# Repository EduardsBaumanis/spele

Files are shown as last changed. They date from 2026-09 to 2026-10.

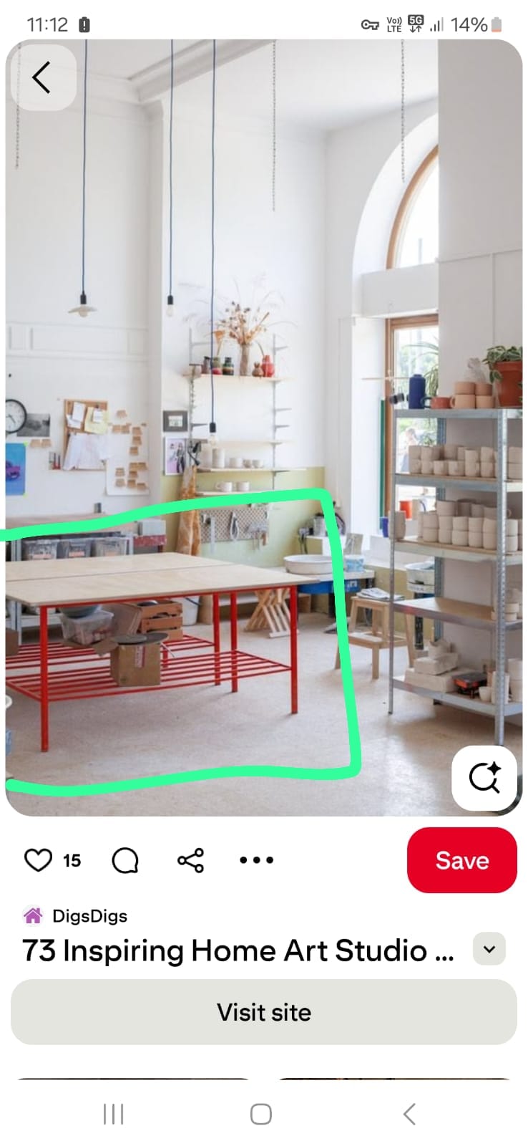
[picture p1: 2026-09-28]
Table.jpeg

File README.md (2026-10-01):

# Keramikas darba galds — vietne GitHub Pages

Latviska dokumentācija galdam 200 × 100 cm. Redakcija F: viena metināta pamatne, 5 cm bērza virsma ar kokskrūvēm no apakšas, astoņas mazas ribas un regulējamas pēdas. Augšējā rāmja nav. Metāla plaukts piemetināts kājām. Visi izgatavošanas izmēri centimetros.

Atveriet **[index.html](index.html)**. Vietnē ir 3D modelis, visi trīs PDF un septiņi SVG rasējumi ar lapu izvēli un tuvināšanu, detaļu tabula un lasāms apraksts. PDF priekšskatījumi ir lokāli attēli; vietnei nav vajadzīgs servera kods, ārējas bibliotēkas vai pārlūka PDF spraudnis. Oriģinālie PDF un SVG ir pieejami lejupielādei.

3D skatā poga **Sadalīt detaļās** atdala visas 37 tērauda detaļas, galda saplākšņa virsmu un četras pēdas; skats automātiski ietilpina visu konstrukciju. Detaļu izmēri saglabājas, atdalījuma attālumi ir ilustratīvi. Poga **Samontēts** atjauno salikto galdu. Atsevišķais slīdnis paceļ tikai noņemamo virsmu. Detaļu sadalījums ir apskates ilustrācija: metinātā pamatne dzīvē neizjaucas.

## Publicēšana GitHub Pages

1. Pievienojiet repozitorijam `index.html`, `.nojekyll`, visu `site-assets/` un `pottery-table/` mapi. Lietojiet šeit esošo mapju struktūru. ZIP arhīvs publicēšanai nav nepieciešams.
2. Nosūtiet šos failus uz sava repozitorija `main` zaru.
3. GitHub atveriet **Settings → Pages → Build and deployment**.
4. Izvēlieties **Deploy from a branch**, zaru **main** un mapi **/(root)**, tad **Save**.
5. Sagaidiet GitHub norādīto vietnes adresi. Projekta vietnei tā parasti ir `https://LIETOTĀJS.github.io/REPOZITORIJS/`.

Visas vietējās saites ir relatīvas, tāpēc vietne darbojas arī repozitorija apakšceļā. Nav vajadzīgs domēns vai GitHub Actions konfigurācija. Šajā uzdevumā vietne ir sagatavota; tā nav nosūtīta uz GitHub vai publicēta.

[GitHub oficiālā publicēšanas instrukcija](https://docs.github.com/en/pages/getting-started-with-github-pages/configuring-a-publishing-source-for-your-github-pages-site).

## Lokāla apskate

Var atvērt `index.html` tieši pārlūkā. Lai pārbaudītu tāpat kā tīmeklī, no šīs mapes palaidiet:

```sh
python3 -m http.server 8000
```

Tad atveriet `http://localhost:8000`. Vietne nelieto `fetch`, tādēļ lokālajiem datiem nav nepieciešams ārējs serveris.

## Dokumentācijas atjaunošana

Izmēri un modeļa dati: `pottery-table/source/design.py`. Rasējumi: `pottery-table/source/drawings.py`. Apraksts: `pottery-table/construction-guide.md`. Vietnes avoti: `pottery-table/source/site/` un `pottery-table/source/website.py`.

Ģenerēšanai vajadzīgs Python 3, `reportlab`, `svglib`, `pypdf`, `pymupdf` un DejaVu Sans vai Windows Arial. No repozitorija saknes:

```sh
python -m pip install -r pottery-table/source/requirements.txt
python -X utf8 pottery-table/source/build.py
```

Komanda atjauno CSV, CAD, visus PDF un SVG, PDF priekšskatījumus, vietni un `pottery-table-workshop-package.zip`. Priekšskatījumi tiek pārrenderēti, ja PDF lapu saturs mainās. Pēc ģenerēšanas publicējiet arī atjaunotos statiskos failus.

Plaukta 200 kg slodze ir projektēšanas un pieņemšanas mērķis, nevis sertificēta nestspēja. Pirms lietošanas jāpārbauda izgatavotie mezgli un pakāpeniska slogošana; pilnas norādes aprakstā.

Pamatne nav izjaucama (180 × 80 × 73 cm); virsma ir noņemama. Pirms izgatavošanas pārbaudiet pārvietošanas ceļu. Gatavam galdam pārbaudiet šuves, pēdu līmeni un šūpošanos, pēc tam slodzi palieliniet pakāpeniski.

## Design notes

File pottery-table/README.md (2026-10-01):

# Keramikas galds — vienkāršā redakcija F

Virsma 200 × 100 × 5 cm, augstums 78 cm. Viena sametināta tērauda pamatne ar plauktu, četras balsta plāksnes, astoņas nelielas ribas un parastas kokskrūves no apakšas. Augšējā rāmja, frēzētu ielaidumu un skrūvētu plaukta savienojumu nav. Kopā 37 tērauda detaļas.

Atveriet [dokumentu vietni](../index.html) vai [3D modeli](index.html). Virsmu var noņemt; kājas un plaukts neizjaucas. Pirms izgatavošanas pārbaudiet viengabala pamatnes 180 × 80 × 73 cm pārvietošanas ceļu.

- [Pilnais PDF](workshop-package.pdf) un [septiņi A3 rasējumi](drawings.pdf).
- [Vienkāršā būvēšanas secība](construction-guide.md) un [izmēru pārbaude](verification.md).
- [Tērauda detaļas](cutting-list.csv), [skrūves un pēdas](hardware-list.csv), [sagatavju sadalījums](stock-cutting.csv), [urbumi](drilling-coordinates.csv).
- [Nesūtīts cenu pieprasījuma melnraksts](supplier-quote-lv.txt).
- [OpenSCAD modelis](model/table.scad) un [modeļa dati](model/design.json).

Visi izgatavošanas izmēri cm. CSV semikols un decimālais komats; JSON/CAD decimālais punkts. Rasējumi: S01 kopskats, S02 balsti, S03 augstumi, S04 kāju galvas, S05 plaukts, S06 kokskrūves, S07 metināšanas secība. Izmantojiet tikai redakciju F.

200 kg plauktam un 200 kg vienmērīgi uz virsmas ir projektēšanas mērķi, nevis sertificēta nestspēja. Pārbaudiet šuves, pēdu saskari un tukša galda šūpošanos; slodzi palieliniet pakāpeniski. Šaubīgas šuves parādiet pieredzējušam metinātājam. Masa un pārbaudes robežas dotas verification.md.

## Atkārtota ģenerēšana

Python 3; reportlab, svglib, pypdf un pymupdf; DejaVu Sans vai Windows Arial. No projekta saknes:

```sh
python -m pip install -r pottery-table/source/requirements.txt
python -X utf8 pottery-table/source/build.py
```

Komanda atjauno CSV, modeli, vietni, PDF, SVG, priekšskatījumus un ZIP. Avoti source/design.py, source/drawings.py un construction-guide.md. 3D skatā poga **Sadalīt detaļās** atdala visas 37 tērauda detaļas, virsmu un četras pēdas, automātiski ietilpinot tās skatā. **Samontēts** atjauno salikto galdu. Detaļu izmēri nemainās; sadalījums ir tikai ilustrācija, jo pamatne ir sametināta. Atsevišķais slīdnis paceļ tikai noņemamo virsmu. OpenSCAD modelis šajā vidē nav kompilēts.

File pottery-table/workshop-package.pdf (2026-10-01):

PT-200 / IZGATAVOŠANAS DOKUMENTĀCIJA

Redakcija F · 2026-10-01 · visi izmēri cm | 1

# Vienkāršs, masīvs keramikas galds

Redakcija F · 2026. gada 1. oktobris.

Virsma 200 × 100 × 5 cm; augstums 78 cm. Visi izmēri šeit ir centimetros. M16 ir standarta vītnes apzīmējums. Tas pats 50 mm bērza saplāksnis, vienkāršāka izgatavošana.

## Ko būvējam

Vienu sametinātu tērauda pamatni ar četrām kājām un zemu metāla plauktu. Uz kājām četras plakanas balsta plāksnes; pie katras divas nelielas trīsstūra ribas. Virsmu pieskrūvē no apakšas ar parastām kokskrūvēm un paplāksnēm. Darba virspuse paliek gluda.

Augšējā rāmja nav. Nav jāfrēzē metāla ielaidumi, jāurbj cauri virsmai vai jāsalāgo skrūvēti plaukta mezgli. Kājas un plaukts neizjaucas; noņemt var tikai virsmu un izskrūvēt pēdas. Tērauda detaļu skaits samazināts no 69 līdz 37.

Pirms metināšanas pārbaudiet, vai viena 180 × 80 × 73 cm pamatne izies pa durvīm un pagriezieniem līdz darba vietai. Ja neizies, sametiniet to galīgajā telpā vai pārskatiet transportēšanas risinājumu pirms materiālu sagatavošanas. Gatavā virsma ir lielāka un jāienes atsevišķi.

## Kas jāsagādā

- Gatavā bērza saplākšņa virsma 200 × 100 × 5, līdzena un bez atslāņojumiem; izgriežama no 250 × 125 × 5 loksnes.
- Kājas: 4 gab. SHS 6 × 6 × 0,3, garums 68,4.
- Plaukta garensijas: 2 gab. RHS 8 × 4 × 0,3, garums 156; 8 vertikāli.
- Plaukta gala sijas: 2 gab. tā paša profila, garums 54; 8 vertikāli.
- Plaukta šķērslīstes: 13 gab. RHS 6 × 4 × 0,3, garums 27; 4 vertikāli.
- Kāju augšējās plāksnes P01: 4 gab. 20 × 20 × 0,8, katrai četri Ø0,9 caurumi. Centri 3 no malām.
- Kāju pēdu plāksnes P02: 4 gab. 6 × 6 × 0,8, katrai Ø1,8 caurums centrā un M16 metināms uzgrieznis.
- Ribas P05: 8 vienādi taisnleņķa trīsstūri ar katetēm 6 un 6, biezums 0,6.
- Virsmai: 16 kvalitatīvas seškanšu galvas kokskrūves Ø0,8 × 4 un 16 paplāksnes, aptuveni 0,2 biezas. Skrūves garums dots zem galvas. Nelietot ģipškartona skrūves.
- 4 M16 regulējamas pēdas ar platiem gumijotiem paliktņiem ap Ø8 un kontruzgriežņiem. Pēdas deklarētā nestspēja vismaz 300 kg katrai pie izmantotā regulējuma.

Vienkāršākais ir metāla tirgotājam pasūtīt gatavos taisnos griezumus, trīsstūrus un izurbtās plāksnes. P01 var izgatavot pēc viena urbšanas šablona; P02 ar uzgriezni var palūgt sagatavot metinātājam. Nav vajadzīga precīza frēzēšana. Pilnie saraksti ir CSV un PDF pielikumā; cenas pieprasījuma melnraksts nav nosūtīts.

Caurulēm pietiek ar vienu 600 cm sagatavi no katra no trim profiliem. Griešanas sarakstā ierēķināts 0,3 zāģējums un 2 rezerve galiem. Profili necinkoti S235; pirms metināšanas notīrīt savienojumu vietas.

## 1. Izveidojiet četras kājas

Piemetiniet M16 uzgriezni P02 augšpusē, kamēr plāksne vēl ir atsevišķi. Pārbaudiet pēdas ieskrūvēšanos. Tad piemetiniet P02 pie kājas apakšas, uzgriezni atstājot caurules iekšpusē.

P01 centrējiet uz kājas augšgala. Katrā kājā pievienojiet divas 6 × 6 trīsstūra ribas: vienu garuma, otru platuma virzienā, abas vērstas uz galda vidu. S04 parādīts pirmais stūris; pārējiem stūriem izvietojumu spoguļojiet. Šuves savieno abas ribas katetes ar kāju un augšējo plāksni. Skrūvju caurumi paliek brīvi stūros.

Caurules gala savienojumu ar plāksni un ribas sametiniet pilnībā, ne tikai pieķeriet. Strādājiet pārmaiņus pretējās pusēs, lai plāksni mazāk savērptu. Tai cieši jāpieguļ virsmai. Uz 0,3 sienas vispirms izmēģiniet metinājumu tāda paša profila atgriezumā; stiprības šuves nenoslīpējiet plānas.

## 2. Sametiniet pamatni ar plauktu

Vispirms izgatavojiet divus vienādus galus: divas kājas un viena 54 cm gara S02 starp tām. Sijas apakša ir 11,2 virs kājas caurules apakšgala. Ar nominālajām pēdām tas ir 15 virs grīdas, sijas augša 23. Iestatīšanai izmantojiet vienādus atgriezumus kā starplikas.

S02 gali tieši pieguļ kāju iekšējām sienām. Caurules griež taisni; nav slīpu stūru. Pirms griešanas pārbaudiet faktisko aili, bet saglabājiet kāju centru attālumu 60. Galiem cieši jāpieguļ; lielas spraugas neaizpildiet ar nejaušiem metinājuma pikučiem.

Savienojiet abus galus ar divām 156 cm S01 garensijām. To ārmalas ir 32,5 un 67,5 no vienas garās virsmas malas; plaukta kopējais platums 35. Garensijas piemetina starp gala siju iekšējām plaknēm. Visiem četriem nesošajiem profiliem 8 cm vertikāli.

Ievietojiet 13 šķērslīstes, katru 27 garu, ar 4 cm vertikāli. To augšas vienā līmenī ar garensiju augšām. Pirmās līstes ārmalu novietojiet 25 no galda gala; starp līstēm atstājiet 6 spraugu. Vienu 6 cm platu atgriezumu lietojiet kā atkārtojamu šablonu. Režģa zona sanāk 150 × 35.

Vispirms visu tikai pieķeriet. Pārbaudiet taisnleņķus, vienādu augstumu un abas kāju centru diagonāles: nomināli 170,88, starpība ne vairāk par 0,2. Četrām augšējām plāksnēm jāatrodas vienā plaknē. Tad metiniet pārmaiņus pretējās pusēs. Gala siju savienojumus ar kājām un pārējos nesošos savienojumus sametiniet pa pieejamo perimetru. Gatavam galdam ar pieķeršanas punktiem nepietiek.

Slēgtajiem profiliem paredzētos ventilācijas urbumus skatiet koordinātu sarakstā; atveres izveido pirms profila aizmetināšanas. Ja pamatni pulverkrāsosiet, ventilāciju un noteci saskaņojiet ar krāsotāju. Metāla režģa augšējās malas noslīpējiet gludas, lai tās neplēstu māla maisus.

## 3. Pieskrūvējiet virsmu no apakšas

Saplākšņa malas noapaļojiet vai rūpīgi noslīpējiet. Aizsargājiet abas puses, malas un urbumus pret mitrumu ar izvēlētu apdari pēc tās ražotāja instrukcijas.

Droši atbalstiet virsmu ar apakšu uz augšu un uzlieciet pamatni. Tā jānovieto centrā: P01 ārmalas 10 no virsmas malām; kāju centri 20 no malām. Pārnesiet 16 caurumu vietas caur P01. Ja izmantojat koordinātas: X=13;27;173;187 un Y=13;27;73;87, visas kombinācijas. Tie ir skati no augšas; uz apgrieztas virsmas orientāciju pārbaudiet ar pašu pamatni.

Izurbiet priekšurbumus no apakšas ar dziļuma ierobežotāju līdz 3,2. Diametru nosaka izvēlētās kokskrūves ražotājs; izmēģiniet vienu skrūvi tāda paša saplākšņa atgriezumā. Pievienojiet paplāksnes un ieskrūvējiet Ø0,8 × 4 kokskrūves. Nomināli 0,8 plāksne + 0,2 paplāksne + 3 ieskrūvējums = 4, tāpēc līdz virspusei paliek ap 2 cm. Cauri darba virsmai nav jāurbj.

Pēdējo pievilkšanu veiciet ar rokas atslēgu, līdz savienojums ciešs. Nesabojājiet vītni kokā ar pārmērīgu spēku. Starp plāksni un virsmu nelieciet mīkstu putu lenti. Virsmas svaru balsta plāksnes; skrūves notur to vietā. Smago galdu ceļ aiz tērauda pamatnes, nevis saplākšņa malas. Ja virsmu bieži noņemsiet, pārbaudiet, vai kokskrūvju vietas nav izļodzītas.

## 4. Noregulējiet pēdas un pārbaudiet galdu

Nominālais augstums: 3 pēda + 0,8 P02 + 68,4 kāja + 0,8 P01 + 5 virsma = 78. Ja faktiskās virsmas biezums ir t, pēdas augstums līdz P02 apakšai ir 8 − t. Pie t=4,81–5,15 tas ir 3,19–2,85. Izvēlieties pēdu, kurai šajā diapazonā paliek pilna uzgriežņa vītnes saķere. Augstuma maiņa nedaudz maina arī plaukta augstumu.

- Vēl pirms virsmas uzlikšanas apskatiet šuves un pārbaudiet tukšo pamatni. Šaubīgu šuvi parādiet pieredzējušam metinātājam, īpaši gala sijas savienojumu ar kāju.
- Galīgajā vietā noregulējiet visas četras pēdas, lai katra stingri balstās uz grīdas. Fiksējiet kontruzgriežņus. Spiediet pārmaiņus katru galda stūri: nedrīkst būt klaboņas vai šūpošanās uz trim kājām.
- Stingri piespiediet tukšu galdu no abām garajām un abām īsajām malām. Šuvēs un plākšņu savienojumos nedrīkst būt redzamas kustības. Ja viss galds slīd, pārbaudiet pēdu saķeri ar grīdu; vajadzības gadījumā izmantojiet grīdai piemērotu fiksāciju.
- Māla maisus pievienojiet pakāpeniski un vienmērīgi pa režģi, nevis visus vienā punktā. Vērojiet šuves, plaukta un virsmas lieci. Pie plaisāšanas, kustības vai paliekošas deformācijas pārtrauciet un novērsiet cēloni.
- Pārbaudiet kokskrūves un pēdu kontruzgriežņus pēc pirmās lietošanas nedēļas un pēc pārvietošanas.

200 kg uz plaukta un 200 kg vienmērīgi uz virsmas saglabāti kā projektēšanas mērķi, nevis pārbaudīta vai sertificēta nestspēja. Metinājumu kvalitāti un faktiskās plātnes lieci nevar garantēt ar detaļu sarakstu; smago paredzēto slodzi izmēģina tikai pēc savienojumu apskates. Galds nav pakāpiens vai sēdvieta.

## Lietošana un rasējumi

Sēdvietu skaitu un izvietojumu pielāgojiet 200 × 100 cm virsmai. Pirms gala metināšanas ar īstajiem krēsliem pārbaudiet vietu ceļiem un pēdām; zemās gala sijas atrodas 15–23 virs grīdas. Divi noņemami 60 × 45 × 2,1 saplākšņa dēļi ar audeklu un mīkstām skavām der māla mīcīšanai. Pēc darba tos noņem un izžāvē.

S01 kopskats; S02 balstu izvietojums; S03 augstumi; S04 vienkāršās kāju galvas; S05 plaukts; S06 kokskrūves no apakšas; S07 metināšanas secība. Precīzie izgatavošanas izmēri ir rasējumos un CSV. Izmantojiet tikai redakciju F; iepriekšējās versijas detaļas nav jāsajauc ar šo.

Aprēķinu piezīmes un automātisko izmēru pārbaužu rezultāti ir verification.md un PDF pielikumā. PDF drukājot pārbaudiet 5 cm kontroles līniju. JSON un CAD viena vienība ir 1 cm. Bērza saplākšņa ražotāja informācija: https://www.finieris.com/products/riga-ply/ .

# Tērauda detaļu saraksts

Gatavie izmēri cm. Taisni gali, izņemot trīsstūrveida ribas. Necinkots S235. Zāģējums pieskaitāms materiāla patēriņam.

Poz. | Detaļa | Profils, cm | Gab. | Gatavais izmērs, cm
L01 | Galda kāja | SHS 6×6×0,3 | 4 | 68,4
S01 | Plaukta garensija; 8 vertikāli | RHS 8×4×0,3 | 2 | 156
S02 | Plaukta gala šķērssija; 8 vertikāli | RHS 8×4×0,3 | 2 | 54
S03 | Plaukta šķērslīste; 4 vertikāli | RHS 6×4×0,3 | 13 | 27
P01 | Kājas balsta plāksne tieši zem saplākšņa | Plāksne 0,8 | 4 | 20 × 20 × 0,8
P02 | Kājas apakšējā plāksne | Plakandzelzs 6×0,8 | 4 | 6 × 6 × 0,8
P05 | Kājas stingrības riba; katetes 6 un 6 | Plāksne 0,6 | 8 | Katetes 6 un 6; biezums 0,6

# Cauruļu sagatavju sadalījums

600 cm sagataves; 0,3 cm zāģējums katrai detaļai; kopā 2 cm rezervē galiem. Plakandzelzs un trīsstūru sagataves aprēķina atsevišķi.

Profils, cm / sagatave | Gatavie garumi, cm | Atlikums, cm
SHS 6×6×0,3 / 1 | L01: 68,4; L01: 68,4; L01: 68,4; L01: 68,4 | 323,2
RHS 8×4×0,3 / 1 | S01: 156; S01: 156; S02: 54; S02: 54 | 176,8
RHS 6×4×0,3 / 1 | S03: 27; S03: 27; S03: 27; S03: 27; S03: 27; S03: 27; S03: 27; S03: 27; S03: 27; S03: 27; S03: 27; S03: 27; S03: 27 | 243,1

## Norādes piegādātājam

Visi norādītie izmēri ir gatavie detaļu izmēri centimetros. Pieskaitīt faktisko zāģējumu, saglabājot detaļu garumus. Marķēt detaļu pozīcijas un noņemt atskabargas. Ja zāģējumam vai galu apgriešanai vajadzīga lielāka rezerve, sadalījumu pārrēķināt.

Atsevišķi precizēt maksu par pilnām sagatavēm, plakandzelzs minimumus, trīsstūru griešanu un piegādi. Apmaksātos atlikumus atdot pasūtītājam. Pievienotajā nesūtītajā pieprasījumā vēl jāieraksta pasūtītāja kontaktinformācija.

# Stiprinājumi un saplāksnis

Pirms urbšanas izvēlēties īstos balstus, metināmos uzgriežņus un kokskrūves ar paplāksnēm. Sausajā montāžā pārbaudīt skrūvju garumus. Skaits gabalos.

Poz. | Sk. | Apraksts | Montāžas un iegādes piezīme
H07 | 4 | M16 metināms uzgrieznis | Kājas iekšpusē virs P02; izvēlēties pirms metināšanas.
H08 | 4 | M16 regulējams balsts; paliktnis ap Ø8 cm; vismaz 300 kg katram | Paliktnis ne augstāks par 2 cm; kāts vismaz 6 cm; regulējums 2,85–3,19 cm no grīdas līdz P02 apakšai.
H09 | 4 | M16 plāns kontruzgrieznis; nomināli 0,8 cm | Ietilpst starp balsta paliktni un P02; pārbaudīt vītnes saķeri.
H10 | 16 | Koka seškanšu skrūve Ø0,8 × 4 cm; garums zem galvas | Kvalitatīva kokskrūve ar rupju vītni; priekšurbums no apakšas pēc ražotāja norādes. Ne ģipškartona skrūve.
H12 | 16 | Paplāksne skrūvei Ø0,8; ārējais Ø ap 2; biezums ap 0,2 cm | Zem P01; nomināli 3 cm skrūves ieiet saplāksnī, ap 2 cm līdz virspusei.
W01 | 1 | Bērza saplāksnis 200×100×5 cm, RIGA PLY BB/WG EXT LN | Gatavā virsma izgriežama no 250×125×5 cm loksnes; loksnes kods 0015001250250000061L. Cenu un pieejamību apstiprināt pirms pasūtīšanas.
W02 | 2 | Bērza saplākšņa darba dēlis 60×45×2,1 cm | Atsevišķs materiāls; noapaļot malas, pārklāt ar noņemamu audeklu.
W03 | 2 | Mazgājams, nostiepts audekla pārvalks | Dēlim W02; regulāri izžāvēt un pēc vajadzības nomainīt.
W04 | 4 | Skavas ar mīkstiem paliktņiem | Atvērums atbilstošs galda virsmai un darba dēlim.

# Pārbaudes un aprēķini

## Kas pārbaudīts datorā

Izpildītas 63 ģeometrijas pārbaudes. Tas nav fiziska galda slodzes tests.

- Katra griešanas saraksta detaļa precīzi atbilst vienam modeļa elementam.
- Augstums bez augšējā rāmja: 3 + 0,8 + 68,4 + 0,8 + 5 = 78 cm.
- Plaukta metāla balsta virsma nomināli 23 cm; saplākšņa klāja nav.
- Augšējā rāmja un P04 modeļa un griešanas sarakstā nav.
- Četras balsta plāksnes, astoņas ribas; nav skrūvēto plaukta mezglu vai iegremdēto plākšņu.
- P01 cieši balsta W01 apakšu pie Z=73.
- Katrai kājai divas uz iekšpusi vērstas ribas; pa vienai X un Y virzienā.
- Visas 16 plākšņu un saplākšņa urbumu asis sakrīt.
- Kokskrūvju un paplākšņu skaits atbilst 16 caurumiem.
- Nav plaukta M12 vai virsmas caurejošo skrūvju uzgriežņu.
- Plaukta gala sija 54 cm aizpilda aili tieši starp kājām.
- S02 abi gali saskaras ar kājām metināšanai bez savienojuma plāksnēm.
- S01 abi gali saskaras ar gala sijām metināšanai.
- Plaukta garensijas 156 cm un šķērslīstes 27 cm precīzi aizpilda ailes.
- Trīspadsmit šķērslīstes ar 12 cm soli un 6 cm spraugām; ārmalas X=25 un 175 cm.
- Centrētais plaukta režģis ietilpst starp gala sijām un kājām.
- 29 cauruļu un plākšņu apvalkiem nav savstarpēju tilpuma pārklāšanos: pārbaudīts.
- Metinātā pamatne ar P01: 180 × 80 cm plānā; augša 73 cm virs grīdas.
- Visi apaļie urbumi ietilpst atbilstošajās detaļu plaknēs.
- SHS 6×6×0,3, sagatave 1: griezumi ietilpst 600 cm, ieskaitot zāģējumu un gala rezervi.
- RHS 8×4×0,3, sagatave 1: griezumi ietilpst 600 cm, ieskaitot zāģējumu un gala rezervi.
- RHS 6×4×0,3, sagatave 1: griezumi ietilpst 600 cm, ieskaitot zāģējumu un gala rezervi.
- Cauruļu sadalījumā katra sagatave uzskaitīta tieši vienu reizi.
- Kokskrūve 4 cm: 0,8 plāksne + 0,2 paplāksne + 3 cm ieskrūvējums.
- Pat bez paplāksnes un ar 0,7 biezu plāksni skrūve nesasniedz virspusi; rezerve vismaz 1,5 cm.
- Virsmas biezuma pielaidei balsta regulējums nepieciešams 2,85–3,19 cm.

## Daudzumi un masa

- 37 tērauda detaļas agrāko 69 vietā; 8 ribas agrāko 16 vietā. Nav P03, P06, M10 vai M12 savienojumu.
- Teorētiskā tērauda masa 64,4 kg; saplāksnim ap 67,2–76,2 kg. Kopā ar pēdām un skrūvēm tukšs galds ap 137–149 kg.
- Masai lietoti ideāli taisnstūra profili un tērauda blīvums 0,00785 kg/cm³; precīzu masu nosaka faktiskie materiāli.

- Saplākšņa masas aplēse pārrēķināta proporcionāli jaunās 200 × 100 × 5 cm virsmas tilpumam, saglabājot iepriekšējo blīvuma diapazonu.
- Trīs 600 cm cauruļu sagataves: pa vienai no katra profila; plāksnes un ribas atsevišķi.

## Stiprinājumi un stingrība

- Kājas un plaukts sametināti vienā pamatnē. S02 54 cm gali tieši saskaras ar kājām; nav skrūvju brīvkustības plaukta savienojumos.
- Pa divām 6 × 6 ribām katras kājas augšā, X un Y virzienā. Virsmas vertikālo slodzi nes četras 20 × 20 plāksnes; kokskrūves notur virsmu pie pamatnes.
- Kokskrūve 4 − P01 0,8 − paplāksne 0,2 = 3 cm kokā; nomināli 2 cm līdz augšpusei. Priekšurbumam dziļuma ierobežotājs 3,2. Pārbaudīt īstās skrūves un priekšurbuma diametru atgriezumā.
- Pirms virsmas uzlikšanas pārbaudīt tukšās pamatnes šūpošanos. Pēc uzlikšanas pārbaudīt vēlreiz, stingri spiežot abos virzienos un stūros. Visas pēdas uz grīdas, kontruzgriežņi pievilkti; šuves un galvu savienojumi nekustas.
- Absolūta nulles kustība nav garantēta: iespējama elastīga izliece un slīdēšana uz konkrētas grīdas. Ja galds slīd, risināt pēdu saķeri vai grīdas fiksāciju, nevis slēpt vaļīgu mezglu ar papildu māla svaru.

## Plaukta siju orientējošs aprēķins

Divas RHS 8 × 4 × 0,3 ar 8 vertikāli. Katras sijas vidū pielikta puse no 260 kg (200 kg maisi un rezerve paša plaukta masai); laidums 160 cm starp kāju centriem. Vienkāršotā shēma pārrēķināta jaunajam galda izmēram.

- I=55,853 cm⁴; E=21000000 N/cm²; spriegums FL/(4×I/4) ap 36,533 MPa; elastīgā izliece FL³/(48EI) ap 0,093 cm.
- Tas nav metinājumu, kājas sienas, kokskrūvju vai visas konstrukcijas nestspējas aprēķins. Vienai līstei 200 kg punktveida slodze nav paredzēta.

## Ko jāpārbauda darbnīcā

- 200 kg vienmērīgi uz plaukta un 200 kg vienmērīgi uz virsmas saglabāti kā projektēšanas mērķi, nevis sertificēta nestspēja. Četros punktos balstītās saplākšņa plātnes izliece un visu savienojumu izturība nav pilnībā aprēķināta.
- Šuves apskatīt pirms slogošanas; nepārliecinošas šuves parādīt pieredzējušam metinātājam. Slodzi likt pakāpeniski, pēc katra posma pārbaudot šuves, kājas un virsmas/plaukta lieci. Pie plaisām, kustības vai paliekošas deformācijas pārtraukt.
- Smago galdu celt aiz tērauda pamatnes vai noņemt virsmu. Pamatne nav izjaucama: 180 × 80 × 73 cm ar nominālajām pēdām.
- Modelī nav šuvju vaļņu vai reālas koka vītnes. OpenSCAD teksts ģenerēts, bet tā kompilācija nav veikta.

## Materiāla atsauce

Ražotāja bērza saplākšņa un stiprināšanas informācija: https://www.finieris.com/products/riga-ply/ un https://www.finieris.com/wp-content/uploads/2026/05/RigaWood_PlywoodHandbook.pdf . Ražotāja loksnes dati paši par sevi nav šī galda nestspējas apstiprinājums.

# Izgatavošanas pārbaudes protokols

Pārbaude | Rezultāts / pārbaudītājs / datums

Virsmas biezums / galīgais augstums

Kāju diagonāles / līdzenums

Skrūves, šuves un regulējamie balsti

Stingri piespiest sānos un stūros / šūpošanās

Plaukts 50 / 100 / 150 / 200 kg; izliece

Virsmas un kopējā slodze; paliekoša deformācija

# Kopskats un galvenie izmēri

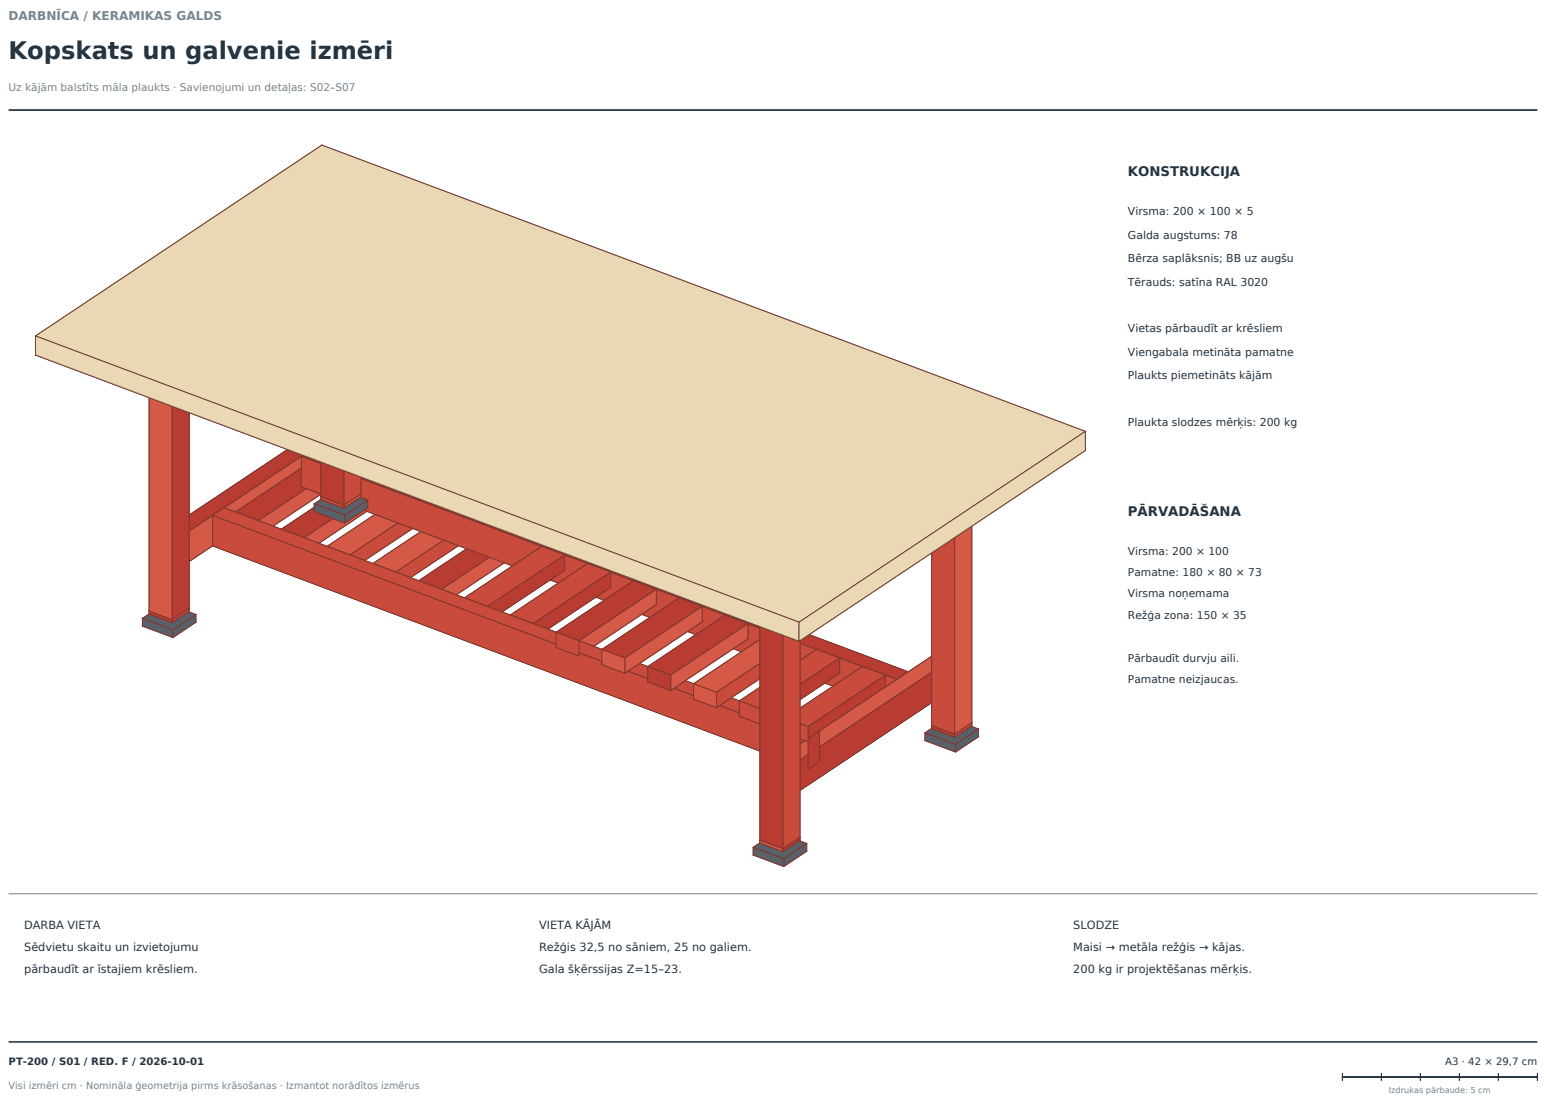
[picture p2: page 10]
PT-200 / S01 / RED. F / 2026-10-01; KONSTRUKCIJA; Virsma: 200 × 100 × 5; Galda augstums: 78; PĀRVADĀŠANA; Virsma: 200 × 100; Pamatne: 180 × 80 × 73; Virsma noņemama; Režģa zona: 150 × 35; Pamatne neizjaucas.; DARBA VIETA; VIETA KĀJĀM; Gala šķērssijas Z=15–23.; SLODZE

DARBNĪCA / KERAMIKAS GALDS

Uz kājām balstīts māla plaukts · Savienojumi un detaļas: S02–S07

Bērza saplāksnis; BB uz augšu

Tērauds: satīna RAL 3020

Vietas pārbaudīt ar krēsliem

Viengabala metināta pamatne

Plaukts piemetināts kājām

Plaukta slodzes mērķis: 200 kg

Pārbaudīt durvju aili.

Sēdvietu skaitu un izvietojumu

Režģis 32,5 no sāniem, 25 no galiem.

Maisi → metāla režģis → kājas.

pārbaudīt ar īstajiem krēsliem.

200 kg ir projektēšanas mērķis.

Visi izmēri cm · Nomināla ģeometrija pirms krāsošanas · Izmantot norādītos izmērus

Izdrukas pārbaude: 5 cm

# Tiešie virsmas balsti — plāns

Mērogs 1:10 uz A3 · Četras atsevišķas kāju plāksnes · Bez augšējā rāmja

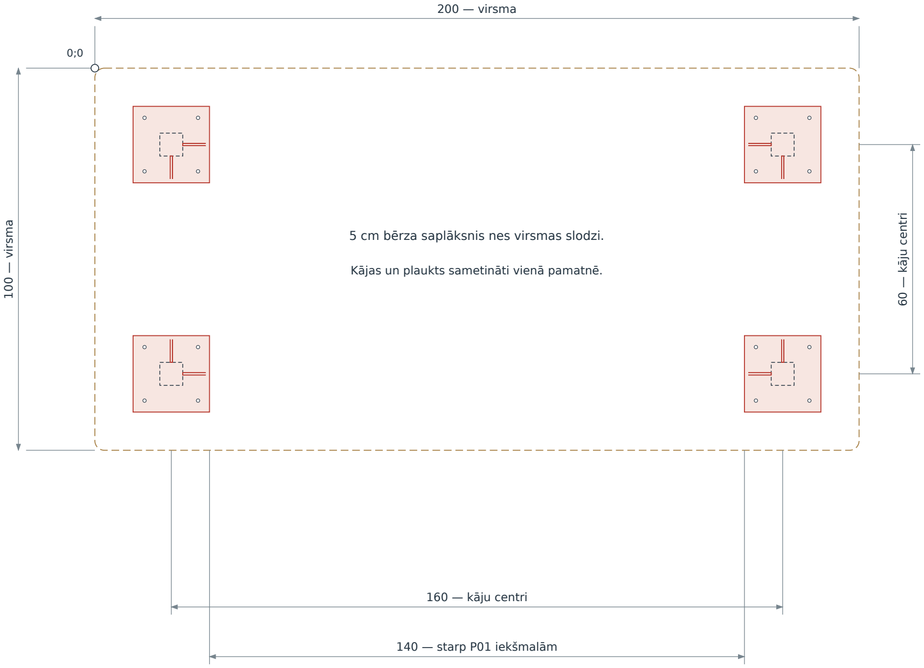
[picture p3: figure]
200 — virsma; 100 — virsma; 160 — kāju centri; 60 — kāju centri; 140 — starp P01 iekšmalām

PT-200 / S02 / RED. F / 2026-10-01

5 cm bērza saplāksnis nes virsmas slodzi.

Kājas un plaukts sametināti vienā pamatnē.

P01: 4 GAB.

20 × 20 × 0,8

X: 10–30; 170–190

Y: 10–30; 70–90

Kāju centri:

X=20 un 180

Y=20 un 80

4 kokskrūves katrā P01.

Urbumu kvadrāts 14 × 14.

Plāksnes augša Z=73.

Bez mīkstas starplikas.

Kāju galvas: S04.

Kāju centru diagonāle: 170,88; diagonāļu starpība ≤0,2. Plāksnēm cieši jābalsta virsma.

Visām P01 cieši jābalsta virsma; spraugas koriģēt ar cietām pilnas saskares starplikām.

Nav perimetra siju vai centrālo šķērssiju. Plaukts savieno visas četras kājas zemāk.

Pārbaudīt tukšu galdu: stingri spiežot abos virzienos, nav šūpošanās, klikšķu vai slīdēšanas.

# Sānskati un augstumu ķēde

Mērogs 1:10 uz A3 · Tieši balstīta 5 cm virsma · Bez mīksta starpslāņa

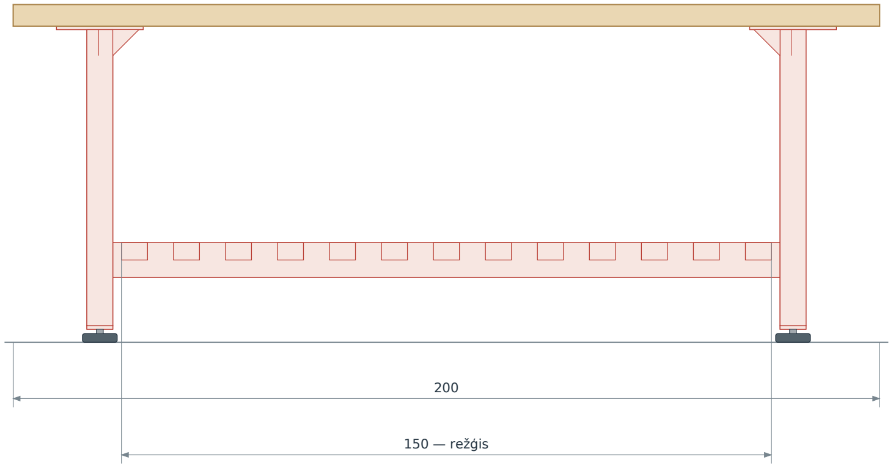
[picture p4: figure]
150 — režģis

PT-200 / S03 / RED. F / 2026-10-01

SKATS NO GARĀS MALAS
SKATS NO GALA

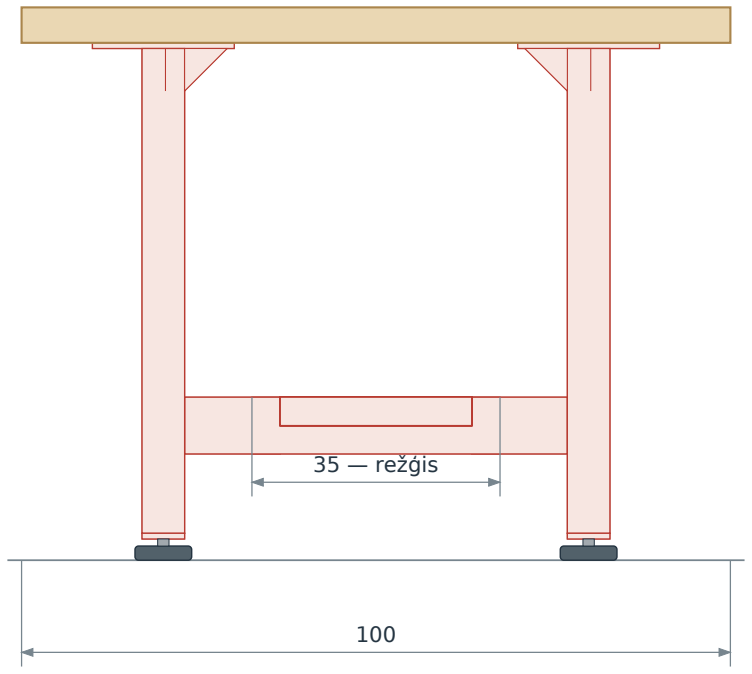
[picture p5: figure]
35 — režģis

78

AUGSTUMI NO GRĪDAS

78 — gluda darba virsma bez caurejošiem urbumiem

73 — virsmas apakša un P01 augša

72,2 — P01 apakša un L01 augša

66,2 — mazo ribu P05 apakšpunkts

L01 garums 68,4; P01 biezums 0,8

3,8 — kājas caurules apakša

3 — P02 apakša; 0 — grīda

3 + 0,8 + 68,4 + 0,8 + 5 = 78

PLAUKTS UN REGULĒŠANA

23 — plaukta metāla balsta virsma.

23 — plaukta tērauda augša; 15 — siju apakša.

Gala šķērssijas atrodas pie X=20 un 180.

Pirms griešanas pārbaudīt krēslus un vietu pēdām.

Balsta augstums = 8 − faktiskais virsmas biezums t.

Pie t=4,81–5,15: balsts 3,19–2,85.

Tērauda augstumi mainās par 5 − t; skatīt aprakstu.

# Vienkāršas kāju plāksnes un pēdas

P01 mērogā 1:2 · Divas nelielas ribas katrai kājai · Kokskrūves no apakšas

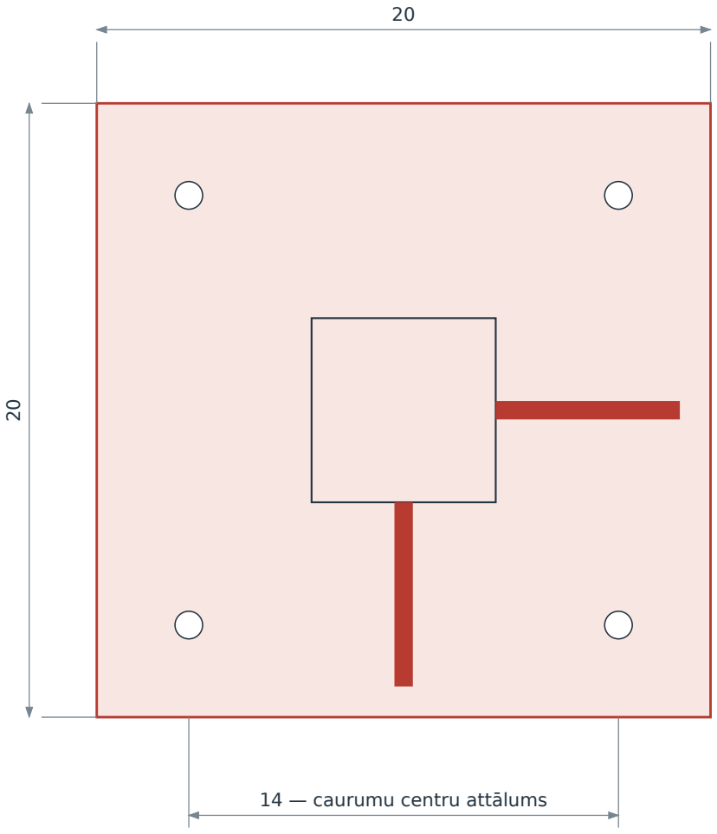
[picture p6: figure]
14 — caurumu centru attālums

PT-200 / S04 / RED. F / 2026-10-01

P01: 4 gab.; 20 × 20 × 0,8.

4 parasti urbumi Ø0,9.

Centri 3 no malām; kāja centrā.

Parādīts stūris X=20; Y=20.

Ribas vērstas uz galda vidu.

Pārējiem stūriem spoguļot.

DIVAS RIBAS, TAISNI CAURUĻU GALI

L01: 6 × 6 × 0,3; garums 68,4.

P05: 8 gab.; katetes 6 × 6; biezums 0,6.

No 6 × 6 kvadrāta iegūst divus trīsstūrus;

ņem vērā zāģējumu vai pasūta gatavus.

Pa vienai ribai X un Y virzienā.

Ribas šuves pie kājas un plāksnes abās pusēs.

P02: 6 × 6 × 0,8; Ø1,8 centrā; M16 uzgrieznis augšpusē.

Uzgriezni piemetina pie atsevišķas P02, tad P02 pie kājas.

4 regulējamas gumijotas pēdas; fiksēt ar kontruzgriežņiem.

# Plaukta metāla rāmis

Plāns un sānskats mērogā 1:10 uz A3 · Plaukts piemetināts tieši kājām; viena tērauda pamatne

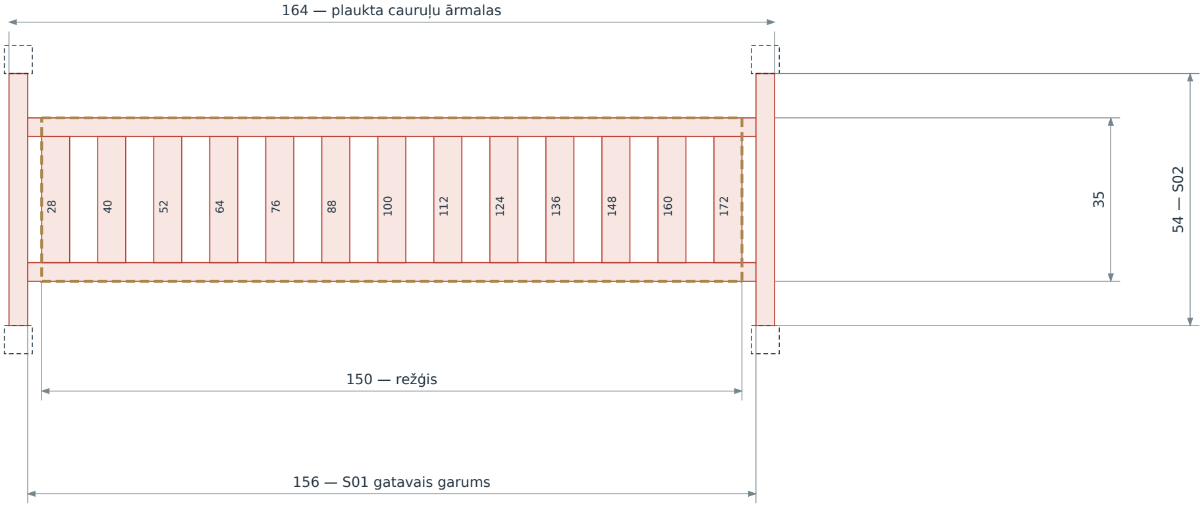
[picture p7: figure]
164 — plaukta cauruļu ārmalas; 150 — režģis; 156 — S01 gatavais garums

PT-200 / S05 / RED. F / 2026-10-01

KOORDINĀTAS

Režģis X: 25–175

Režģis Y: 32,5–67,5

S01 Y: 32,5–36,5

un 63,5–67,5

S01 X: 22–178

S02 X: 18–22

un 178–182

S02 Y: 23–77

S03: 13 gab., garums 27.

Centri X=28,40,…,172.

Solis 12; sprauga 6.

23 — nomināli

Sānskats ar aizsegtajām detaļām; maisus balsta metāls.

S01 un S02: profils 8 × 4 × 0,3 ar 8 vertikāli. S03: profils 6 × 4 × 0,3 ar 4 vertikāli.

Siju augša Z=23; S01/S02 apakša Z=15; S03 apakša Z=19. Saplākšņa klāja nav.

S02 garums 54; galus metina tieši pie kāju iekšējām sienām. Darbu secība: S07.

Līdz 200 kg vienmērīgi izvietotu maisu; neuzskatīt par sertificētu nestspēju.

# Virsma pieskrūvēta no apakšas

Plāns 1:10, skats caur virsmu · Augšpuse paliek gluda · Frēzēšana nav vajadzīga

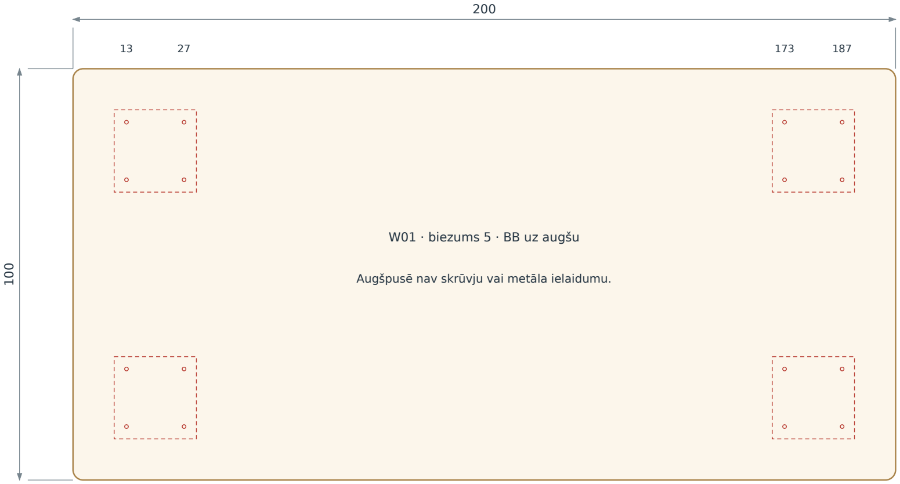
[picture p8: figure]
W01 · biezums 5 · BB uz augšu

PT-200 / S06 / RED. F / 2026-10-01

Augšpusē nav skrūvju vai metāla ielaidumu.

16 KOKSKRŪVES

Ø0,8 × 4, ar seškanšu galvu.

Garums 4 zem galvas.

Katrai parasta paplāksne.

Caurums P01: Ø0,9.

Kokā priekšurbums no apakšas;

Ø pēc skrūves ražotāja.

Dziļums līdz 3,2.

X=13; 27; 173; 187

Y=13; 27; 73; 87

Visas X un Y kombinācijas.

Šķērsgriezums 1:1,67

4 cm skrūve − 0,8 P01 − 0,2 paplāksne = 3 cm kokā.

Virs skrūves paliek ap 2 cm saplākšņa. Neurbt cauri!

Urbja dziļuma ierobežotājs; pirms montāžas izmēģināt atgriezumā.

Pārnest caurumus pēc pamatnes uzlikšanas uz apgrieztās virsmas.

Pievilkt cieši ar rokas atslēgu, neizplēšot vītni kokā.

Virsmas svaru nes plāksnes; skrūves to notur vietā.

Smago galdu celt aiz tērauda pamatnes, nevis saplākšņa malas.

# Viengabala pamatnes montāža

Taisni profilu gali · Gala sijas metina tieši pie kājām · Nav plaukta skrūvju vai slēptu uzgriežņu

PT-200 / S07 / RED. F / 2026-10-01

54 — S02 starp kājām

S02 · 8 vertikāli

1. IZVEIDOT DIVUS VIENĀDUS GALUS

Pa divām kājām un vienai S02 sijai.

S02 apakša 11,2 virs kājas caurules apakšgala.

Ar pēdām tas ir Z=15; sijas augša Z=23.

Izmantot vienādus atgriezumus kā starplikas.

2. SAVIENOT GALUS AR GARSIJĀM

Divas S01, garums 156; 8 vertikāli.

Sijas X=22–178; Y=32,5–36,5 un 63,5–67,5.

Pagaidām tikai pieķert; pārbaudīt taisnleņķus.

3. IEVIETOT 13 ŠĶĒRSLĪSTES

Garums 27; 4 vertikāli; augša vienā līmenī.

6 cm atgriezums kalpo kā spraugas šablons.

4. PĀRBAUDĪT UN SAMETINĀT

Kāju centru diagonāles 170,88; starpība ≤0,2.

P01 plāksnes vienā plaknē uz līdzenas pamatnes.

Metināt pārmaiņus pretējās pusēs.

S02 galus sametināt ar kājām pa perimetru.

Pieķeršanas punkti nav gatavs savienojums.

SKATS NO GALA · 1:5,88

Vienādi gala mezgli pie X=20 un 180.

Abu cauruļu sienas 0,3; piegulošus galus

piegriezt pēc faktiskās ailes.

PIRMS KRĀSOŠANAS

Apskatīt šuves; pārbaudīt pamatni uz grīdas.

Šaubīgas šuves parādīt pieredzējušam metinātājam.

Pamatne ir viena detaļa: 180 × 80 plānā.

Durvju aili un pārvietošanas ceļu pārbaudīt iepriekš.

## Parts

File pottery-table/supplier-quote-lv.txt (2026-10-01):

NESŪTĪTS MELNRAKSTS — cenu piedāvājuma pieprasījums
Kam: biz@metalucentrs.lv
Temats: S235 materiāli un sagarināšana keramikas galdam PT-200, redakcija F

Labdien!

Lūdzu cenu piedāvājumu necinkota S235 materiāliem un sagarināšanai pēc zemāk norādītā saraksta. VISI IZMĒRI CENTIMETROS, arī profilu sienu un plākšņu biezumi. Preču kodi paliek piegādātāja oriģinālie. Šī ir redakcija F: BEZ augšējā rāmja; viengabala metināta pamatne, četras balsta plāksnes un metāla plaukts ar 13 šķērslīstēm.

GATAVĀS DETAĻAS — cm
L01: Galda kāja; SHS 6×6×0,3 cm; 4 gab.; gatavais garums 68,4 cm; kods 06CV06006003000.
S01: Plaukta garensija; 8 vertikāli; RHS 8×4×0,3 cm; 2 gab.; gatavais garums 156 cm; kods 06CV08004003000.
S02: Plaukta gala šķērssija; 8 vertikāli; RHS 8×4×0,3 cm; 2 gab.; gatavais garums 54 cm; kods 06CV08004003000.
S03: Plaukta šķērslīste; 4 vertikāli; RHS 6×4×0,3 cm; 13 gab.; gatavais garums 27 cm; kods 06CV06004003000.
P01: Kājas balsta plāksne tieši zem saplākšņa; Plāksne 0,8 cm; 4 gab.; 20 × 20 × 0,8 cm.
P02: Kājas apakšējā plāksne; Plakandzelzs 6×0,8 cm; 4 gab.; 6 × 6 × 0,8 cm; kods 05PL08006000.
P05: Kājas stingrības riba; katetes 6 un 6; Plāksne 0,6 cm; 8 gab.; taisnleņķa trīsstūris; katetes 6 un 6 cm; biezums 0,6 cm.

LŪDZU PRECIZĒT:
1. Materiālu pieejamību, sagatavošanas termiņu un piegādi.
2. Materiālu, griešanas, atskabargu noņemšanas un piegādes izmaksas atsevišķi; norādīt PVN.
3. Vai gatavā garuma pielaide ±0,1 cm un perpendikulāri gali ir nodrošināmi. Zāģējumu pieskaitīt sagataves patēriņam, saglabājot gatavo detaļu izmērus.
4. Vai maksā par nogrieztajām detaļām vai pilnām sagatavēm; lūdzu atdot apmaksātos atlikumus.
5. Atsevišķu cenu P05 trīsstūriem ar norādītajiem gatavajiem izmēriem.
6. Ja iespējama vienkāršu apaļu urbumu izgatavošana — atsevišķu cenu pēc rasējumiem. Standarta sagarināšanā urbšana nav pieņemta kā iekļauta.
7. Ja izmantojat citus materiālu garumus vai zāģējuma platumu, lūdzu pārrēķināt patēriņu, nemainot gatavos izmērus.

Pielikumi: cutting-list.csv; stock-cutting.csv; drawings.pdf; drilling-coordinates.csv.
Plānotais cauruļu iepirkums: 1 × 600 cm profilam 8×4×0,3 cm; 1 × 600 cm profilam 6×4×0,3 cm; 1 × 600 cm profilam 6×6×0,3 cm.
Sadalījumā pieņemts zāģējums 0,3 cm katrai detaļai un 2 cm kopēja gala rezerve katrai 600 cm sagatavei. Plakandzelzs un trīsstūru sagataves aprēķināt atsevišķi.

Šis ir cenu piedāvājuma pieprasījums; pasūtījums tiks apstiprināts atsevišķi. Piegādes adresi norādīsim pirms pasūtīšanas.

Ar cieņu,
[Vārds, tālrunis]

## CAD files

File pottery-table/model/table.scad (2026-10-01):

// PT-200 / Redakcija F / visas koordinātas cm; 1 vienība = 1 cm.
// Izveidots no source/design.py. Cauruļu stūri un stiprinājumi vienkāršoti.
// Šuves nav modelētas; rasējumos dotās prasības ir spēkā. Bez augšējā rāmja.
$fn=36;
show_top=true;
show_shelf=true;
show_hardware=true;
exploded=0; // Tikai ilustrācijai; samontētā stāvoklī 0.
top_thickness=5; // Faktiski 4.81..5.15; galda augša paliek Z=78.
dz=5-top_thickness;
module steel(group) { translate([0,0,dz]) color([.73,.12,.08]) children(); }
module washer(x,y,z,od,id,h) {translate([x,y,z]) difference(){cylinder(d=od,h=h);translate([0,0,-.01])cylinder(d=id,h=h+.02);}}
module hexnut(x,y,z,af,h,bore) {translate([x,y,z]) difference(){cylinder(d=af/cos(30),h=h,$fn=6);translate([0,0,-.01])cylinder(d=bore,h=h+.02);}}
module bolt(x,y,z,diam,length,af,head) {translate([x,y,z]) {cylinder(d=diam,h=length);translate([0,0,-head])cylinder(d=af/cos(30),h=head,$fn=6);}}
module deck(x,y,z,l,w,t,r) {color([.89,.77,.55]) translate([x,y,z]) linear_extrude(t) hull() for(a=[r,l-r],b=[r,w-r]) translate([a,b]) circle(r=r);}
pilot_diameter=.5; // Ilustratīvi; priekšurbuma Ø pēc kokskrūves ražotāja.
if(show_top) difference(){deck(0,0,78-top_thickness+exploded,200,100,top_thickness,2.5);
translate([13,13,78-top_thickness+exploded-.01]) cylinder(d=pilot_diameter,h=3.21);
translate([13,27,78-top_thickness+exploded-.01]) cylinder(d=pilot_diameter,h=3.21);
translate([27,13,78-top_thickness+exploded-.01]) cylinder(d=pilot_diameter,h=3.21);
translate([27,27,78-top_thickness+exploded-.01]) cylinder(d=pilot_diameter,h=3.21);
translate([173,13,78-top_thickness+exploded-.01]) cylinder(d=pilot_diameter,h=3.21);
translate([173,27,78-top_thickness+exploded-.01]) cylinder(d=pilot_diameter,h=3.21);
translate([187,13,78-top_thickness+exploded-.01]) cylinder(d=pilot_diameter,h=3.21);
translate([187,27,78-top_thickness+exploded-.01]) cylinder(d=pilot_diameter,h=3.21);
translate([13,73,78-top_thickness+exploded-.01]) cylinder(d=pilot_diameter,h=3.21);
translate([13,87,78-top_thickness+exploded-.01]) cylinder(d=pilot_diameter,h=3.21);
translate([27,73,78-top_thickness+exploded-.01]) cylinder(d=pilot_diameter,h=3.21);
translate([27,87,78-top_thickness+exploded-.01]) cylinder(d=pilot_diameter,h=3.21);
translate([173,73,78-top_thickness+exploded-.01]) cylinder(d=pilot_diameter,h=3.21);
translate([173,87,78-top_thickness+exploded-.01]) cylinder(d=pilot_diameter,h=3.21);
translate([187,73,78-top_thickness+exploded-.01]) cylinder(d=pilot_diameter,h=3.21);
translate([187,87,78-top_thickness+exploded-.01]) cylinder(d=pilot_diameter,h=3.21);
}
// P01-1
steel("legs") {
difference(){
translate([10,10,72.2]) cube([20,20,0.8]);
translate([13,13,72.19]) cylinder(d=0.9,h=0.8200000000000001);
translate([13,27,72.19]) cylinder(d=0.9,h=0.8200000000000001);
translate([27,13,72.19]) cylinder(d=0.9,h=0.8200000000000001);
translate([27,27,72.19]) cylinder(d=0.9,h=0.8200000000000001);
}
}
// L01-1
steel("legs") {
difference(){
translate([17,17,3.8]) cube([6,6,68.4]);
translate([17.3,17.3,3.79]) cube([5.4,5.4,68.42]);
}
}
// P02-1
steel("legs") {
difference(){
translate([17,17,3]) cube([6,6,0.8]);
translate([20,20,2.99]) cylinder(d=1.8,h=0.8200000000000001);
}
}
// P05-1-1
steel("legs") {
polyhedron(points=[[23.0, 19.7, 72.2], [29.0, 19.7, 72.2], [23.0, 19.7, 66.2], [23.0, 20.3, 72.2], [29.0, 20.3, 72.2], [23.0, 20.3, 66.2]],faces=[[0,1,2],[3,5,4],[0,3,4,1],[1,4,5,2],[2,5,3,0]]);
}
// P05-1-2
steel("legs") {
polyhedron(points=[[20.3, 23.0, 72.2], [20.3, 29.0, 72.2], [20.3, 23.0, 66.2], [19.7, 23.0, 72.2], [19.7, 29.0, 72.2], [19.7, 23.0, 66.2]],faces=[[0,1,2],[3,5,4],[0,3,4,1],[1,4,5,2],[2,5,3,0]]);
}
// P01-2
steel("legs") {
difference(){
translate([170,10,72.2]) cube([20,20,0.8]);
translate([173,13,72.19]) cylinder(d=0.9,h=0.8200000000000001);
translate([173,27,72.19]) cylinder(d=0.9,h=0.8200000000000001);
translate([187,13,72.19]) cylinder(d=0.9,h=0.8200000000000001);
translate([187,27,72.19]) cylinder(d=0.9,h=0.8200000000000001);
}
}
// L01-2
steel("legs") {
difference(){
translate([177,17,3.8]) cube([6,6,68.4]);
translate([177.3,17.3,3.79]) cube([5.4,5.4,68.42]);
}
}
// P02-2
steel("legs") {
difference(){
translate([177,17,3]) cube([6,6,0.8]);
translate([180,20,2.99]) cylinder(d=1.8,h=0.8200000000000001);
}
}
// P05-2-3
steel("legs") {
polyhedron(points=[[177.0, 20.3, 72.2], [171.0, 20.3, 72.2], [177.0, 20.3, 66.2], [177.0, 19.7, 72.2], [171.0, 19.7, 72.2], [177.0, 19.7, 66.2]],faces=[[0,1,2],[3,5,4],[0,3,4,1],[1,4,5,2],[2,5,3,0]]);
}
// P05-2-2
steel("legs") {
polyhedron(points=[[180.3, 23.0, 72.2], [180.3, 29.0, 72.2], [180.3, 23.0, 66.2], [179.7, 23.0, 72.2], [179.7, 29.0, 72.2], [179.7, 23.0, 66.2]],faces=[[0,1,2],[3,5,4],[0,3,4,1],[1,4,5,2],[2,5,3,0]]);
}
// P01-3
steel("legs") {
difference(){
translate([10,70,72.2]) cube([20,20,0.8]);
translate([13,73,72.19]) cylinder(d=0.9,h=0.8200000000000001);
translate([13,87,72.19]) cylinder(d=0.9,h=0.8200000000000001);
translate([27,73,72.19]) cylinder(d=0.9,h=0.8200000000000001);
translate([27,87,72.19]) cylinder(d=0.9,h=0.8200000000000001);
}
}
// L01-3
steel("legs") {
difference(){
translate([17,77,3.8]) cube([6,6,68.4]);
translate([17.3,77.3,3.79]) cube([5.4,5.4,68.42]);
}
}
// P02-3
steel("legs") {
difference(){
translate([17,77,3]) cube([6,6,0.8]);
translate([20,80,2.99]) cylinder(d=1.8,h=0.8200000000000001);
}
}
// P05-3-1
steel("legs") {
polyhedron(points=[[23.0, 79.7, 72.2], [29.0, 79.7, 72.2], [23.0, 79.7, 66.2], [23.0, 80.3, 72.2], [29.0, 80.3, 72.2], [23.0, 80.3, 66.2]],faces=[[0,1,2],[3,5,4],[0,3,4,1],[1,4,5,2],[2,5,3,0]]);
}
// P05-3-4
steel("legs") {
polyhedron(points=[[19.7, 77.0, 72.2], [19.7, 71.0, 72.2], [19.7, 77.0, 66.2], [20.3, 77.0, 72.2], [20.3, 71.0, 72.2], [20.3, 77.0, 66.2]],faces=[[0,1,2],[3,5,4],[0,3,4,1],[1,4,5,2],[2,5,3,0]]);
}
// P01-4
steel("legs") {
difference(){
translate([170,70,72.2]) cube([20,20,0.8]);
translate([173,73,72.19]) cylinder(d=0.9,h=0.8200000000000001);
translate([173,87,72.19]) cylinder(d=0.9,h=0.8200000000000001);
translate([187,73,72.19]) cylinder(d=0.9,h=0.8200000000000001);
translate([187,87,72.19]) cylinder(d=0.9,h=0.8200000000000001);
}
}
// L01-4
steel("legs") {
difference(){
translate([177,77,3.8]) cube([6,6,68.4]);
translate([177.3,77.3,3.79]) cube([5.4,5.4,68.42]);
}
}
// P02-4
steel("legs") {
difference(){
translate([177,77,3]) cube([6,6,0.8]);
translate([180,80,2.99]) cylinder(d=1.8,h=0.8200000000000001);
}
}
// P05-4-3
steel("legs") {
polyhedron(points=[[177.0, 80.3, 72.2], [171.0, 80.3, 72.2], [177.0, 80.3, 66.2], [177.0, 79.7, 72.2], [171.0, 79.7, 72.2], [177.0, 79.7, 66.2]],faces=[[0,1,2],[3,5,4],[0,3,4,1],[1,4,5,2],[2,5,3,0]]);
}
// P05-4-4
steel("legs") {
polyhedron(points=[[179.7, 77.0, 72.2], [179.7, 71.0, 72.2], [179.7, 77.0, 66.2], [180.3, 77.0, 72.2], [180.3, 71.0, 72.2], [180.3, 77.0, 66.2]],faces=[[0,1,2],[3,5,4],[0,3,4,1],[1,4,5,2],[2,5,3,0]]);
}
// S01-1
if(show_shelf) steel("shelf") {
difference(){
translate([22,32.5,15]) cube([156,4,8]);
translate([21.99,32.8,15.3]) cube([156.02,3.4,7.4]);
translate([100,34.5,14.99]) cylinder(d=0.6,h=0.32);
}
}
// S01-2
if(show_shelf) steel("shelf") {
difference(){
translate([22,63.5,15]) cube([156,4,8]);
translate([21.99,63.8,15.3]) cube([156.02,3.4,7.4]);
translate([100,65.5,14.99]) cylinder(d=0.6,h=0.32);
}
}
// S02-1
if(show_shelf) steel("shelf") {
difference(){
translate([18,23,15]) cube([4,54,8]);
translate([18.3,22.99,15.3]) cube([3.4,54.02,7.4]);
translate([20,50,14.99]) cylinder(d=0.6,h=0.32);
}
}
// S02-2
if(show_shelf) steel("shelf") {
difference(){
translate([178,23,15]) cube([4,54,8]);
translate([178.3,22.99,15.3]) cube([3.4,54.02,7.4]);
translate([180,50,14.99]) cylinder(d=0.6,h=0.32);
}
}
// S03-1
if(show_shelf) steel("shelf") {
difference(){
translate([25,36.5,19]) cube([6,27,4]);
translate([25.3,36.49,19.3]) cube([5.4,27.02,3.4]);
translate([28,50,18.99]) cylinder(d=0.6,h=0.32);
}
}
// S03-2
if(show_shelf) steel("shelf") {
difference(){
translate([37,36.5,19]) cube([6,27,4]);
translate([37.3,36.49,19.3]) cube([5.4,27.02,3.4]);
translate([40,50,18.99]) cylinder(d=0.6,h=0.32);
}
}
// S03-3
if(show_shelf) steel("shelf") {
difference(){
translate([49,36.5,19]) cube([6,27,4]);
translate([49.3,36.49,19.3]) cube([5.4,27.02,3.4]);
translate([52,50,18.99]) cylinder(d=0.6,h=0.32);
}
}
// S03-4
if(show_shelf) steel("shelf") {
difference(){
translate([61,36.5,19]) cube([6,27,4]);
translate([61.3,36.49,19.3]) cube([5.4,27.02,3.4]);
translate([64,50,18.99]) cylinder(d=0.6,h=0.32);
}
}
// S03-5
if(show_shelf) steel("shelf") {
difference(){
translate([73,36.5,19]) cube([6,27,4]);
translate([73.3,36.49,19.3]) cube([5.4,27.02,3.4]);
translate([76,50,18.99]) cylinder(d=0.6,h=0.32);
}
}
// S03-6
if(show_shelf) steel("shelf") {
difference(){
translate([85,36.5,19]) cube([6,27,4]);
translate([85.3,36.49,19.3]) cube([5.4,27.02,3.4]);
translate([88,50,18.99]) cylinder(d=0.6,h=0.32);
}
}
// S03-7
if(show_shelf) steel("shelf") {
difference(){
translate([97,36.5,19]) cube([6,27,4]);
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

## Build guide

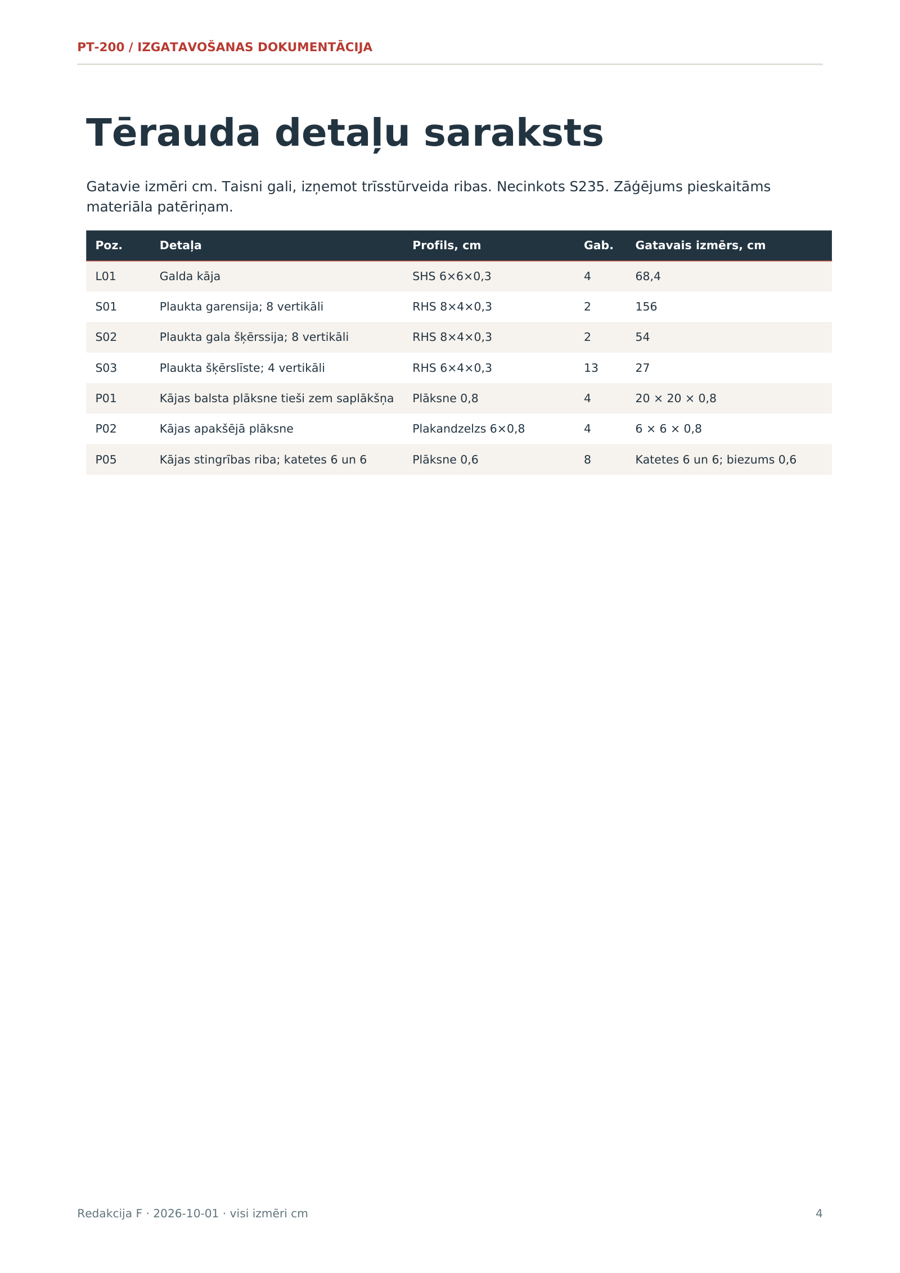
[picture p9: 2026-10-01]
site-assets/pdf-pages/guide-04.png

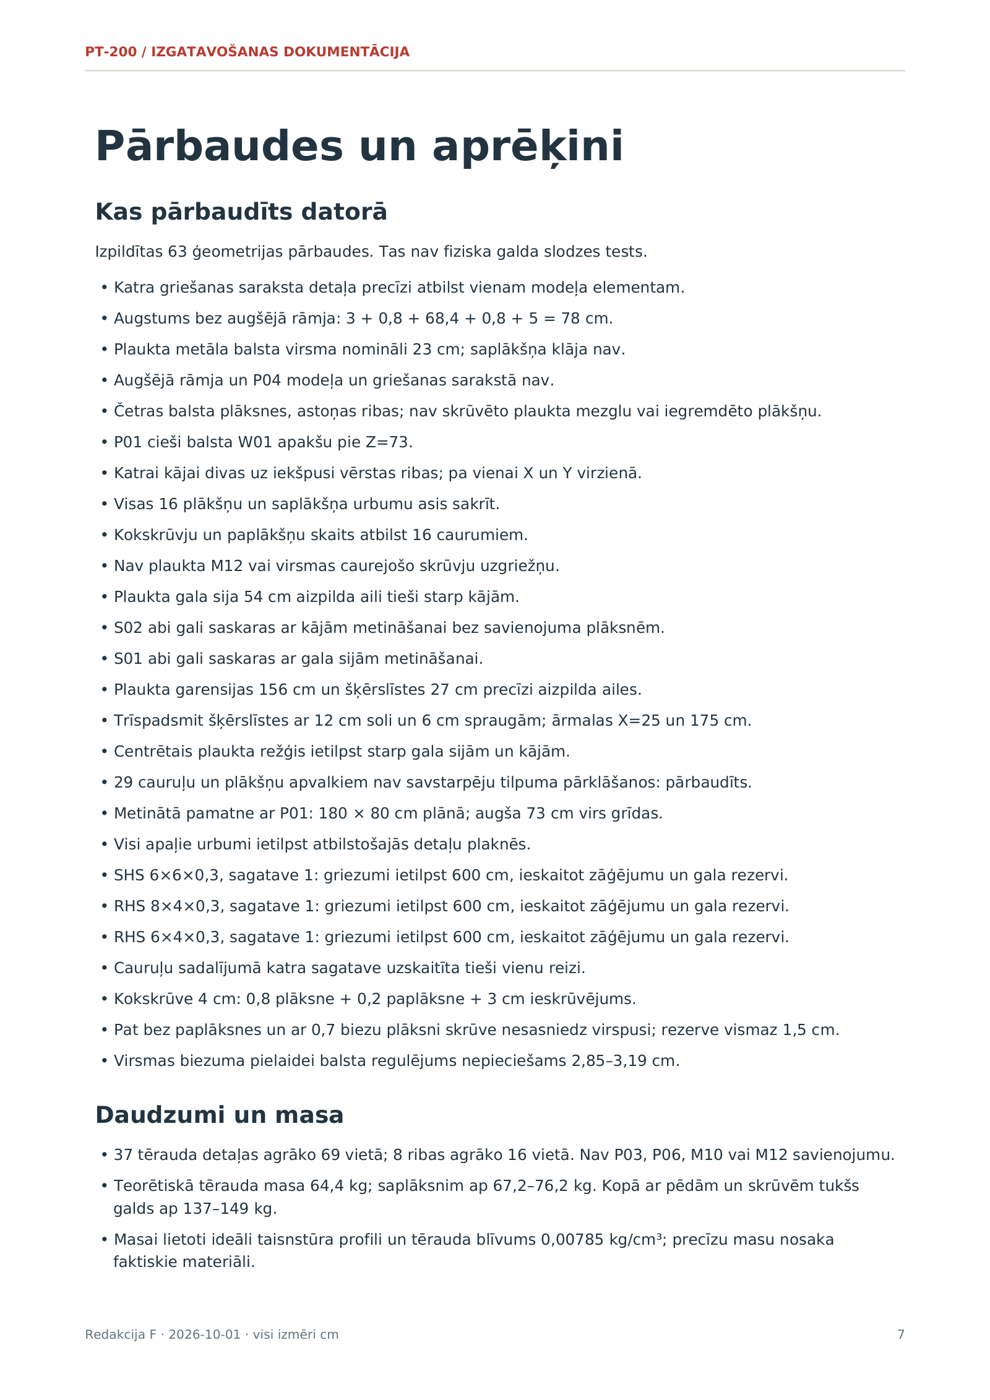
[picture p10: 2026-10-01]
site-assets/pdf-pages/guide-07.png

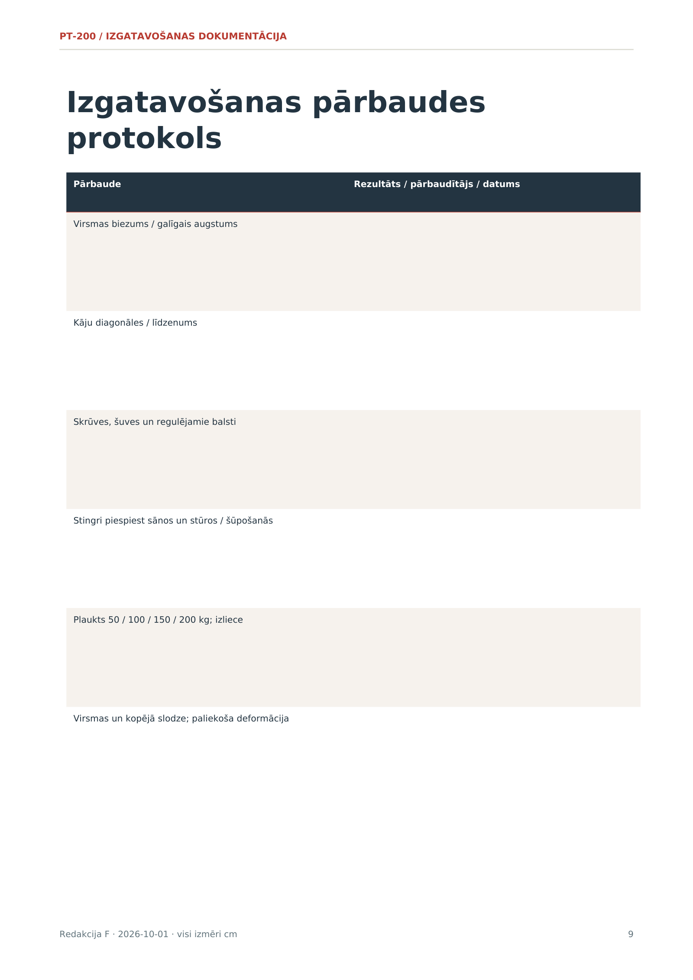
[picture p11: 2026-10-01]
site-assets/pdf-pages/guide-09.png

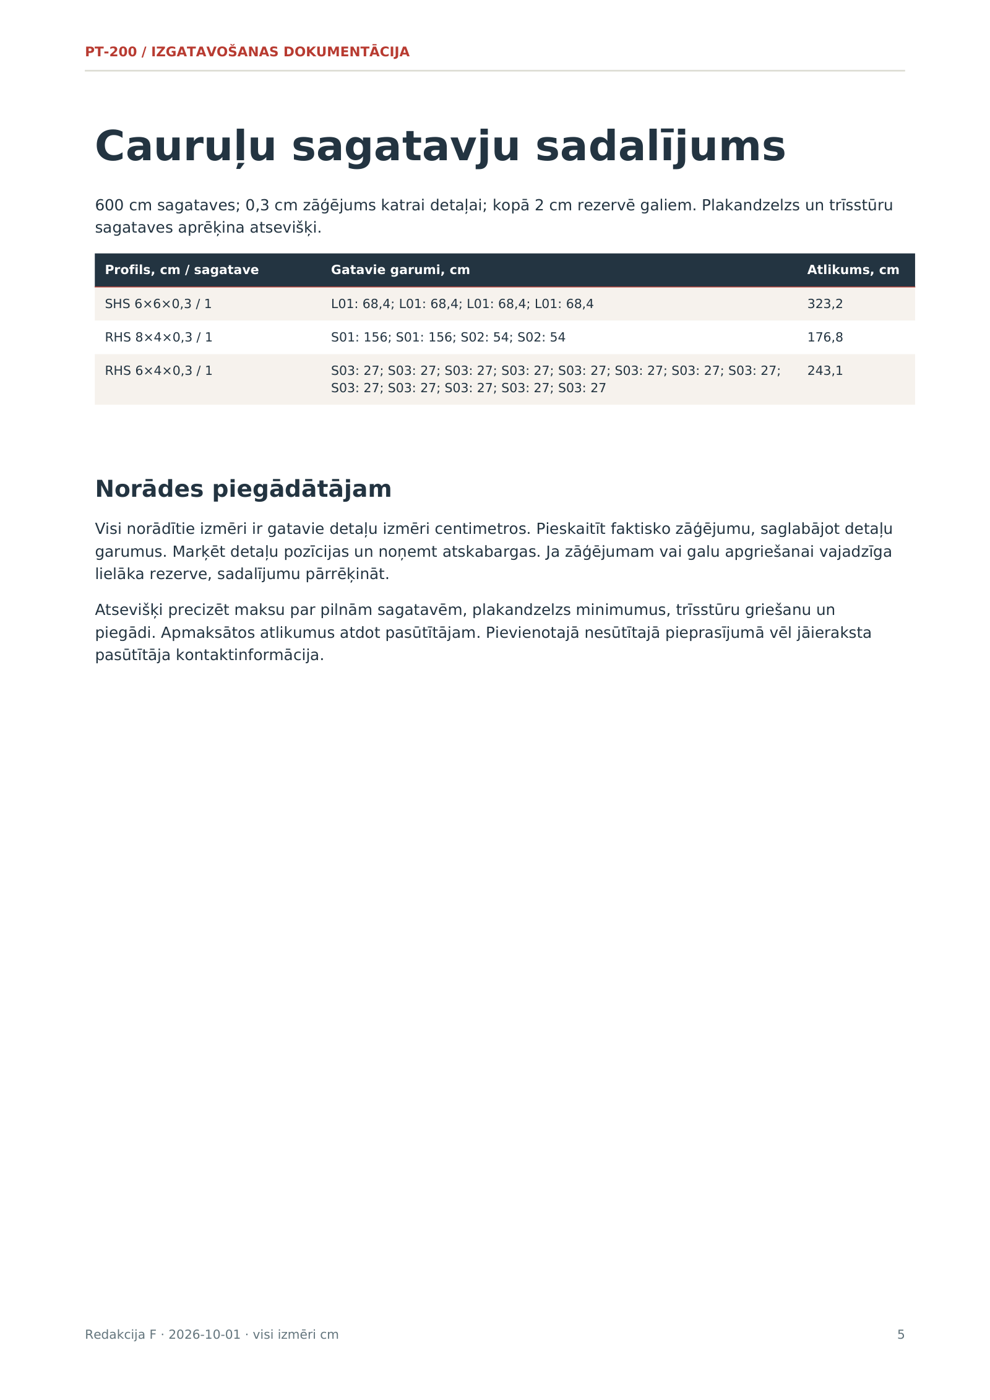
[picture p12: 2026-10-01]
site-assets/pdf-pages/guide-05.png

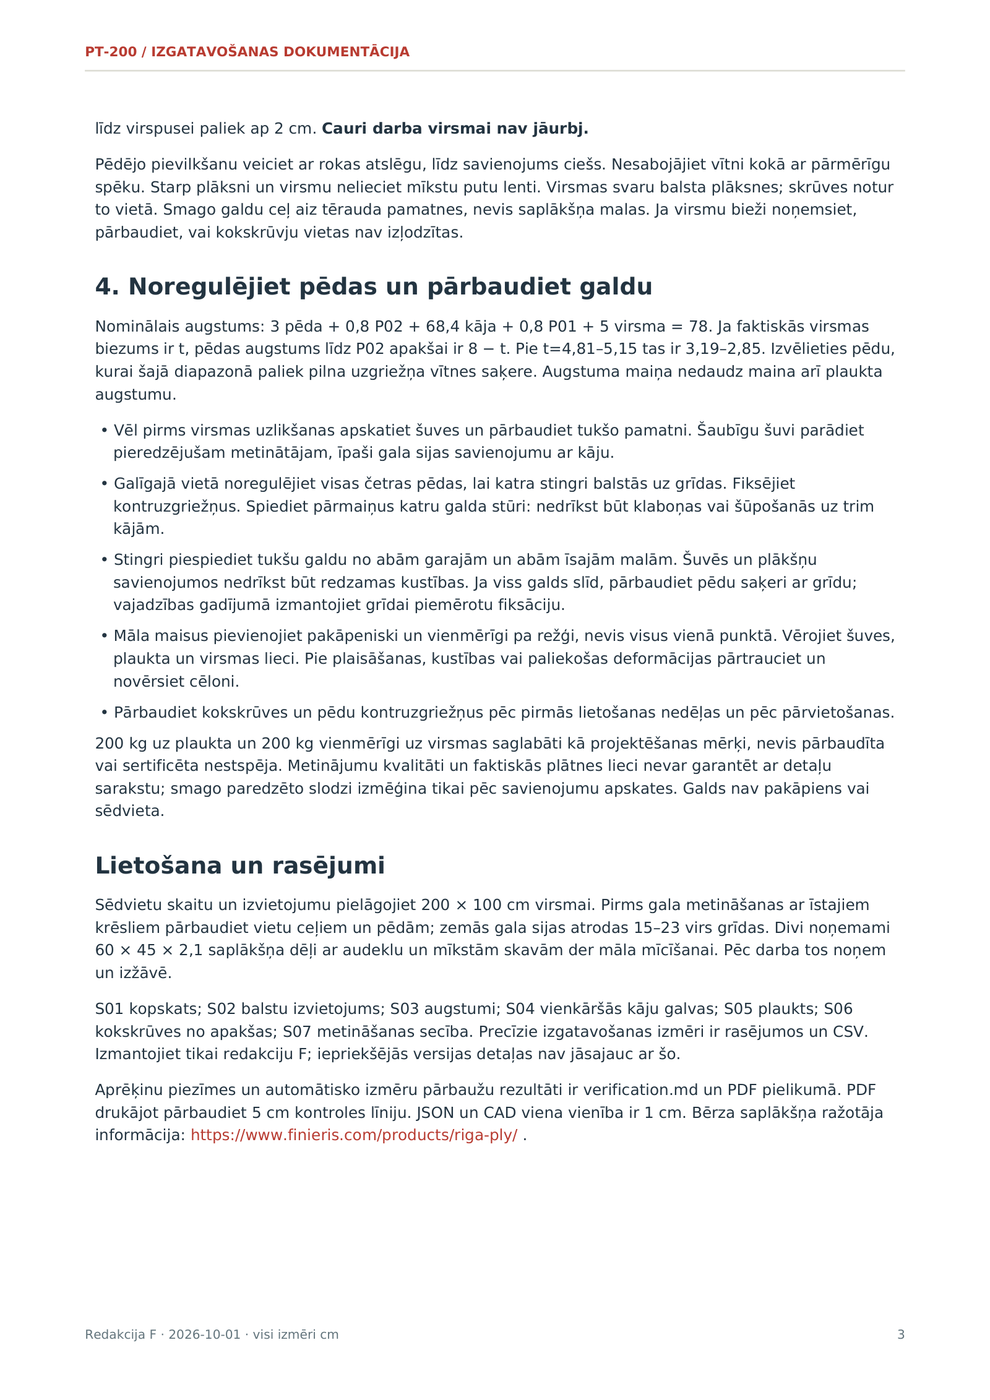
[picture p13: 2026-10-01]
site-assets/pdf-pages/guide-03.png

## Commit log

2026-09-28 Pretty good
    [cutting-list.csv, drilling-coordinates.csv, hardware-list.csv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]
2026-09-28 Done web
    [cutting-list.csv, drilling-coordinates.csv, hardware-list.csv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]
2026-09-28 Dēlis
    [cutting-list.csv, drilling-coordinates.csv, hardware-list.csv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]
2026-09-30 Vienkārsots
    [cutting-list.csv, drilling-coordinates.csv, hardware-list.csv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]
2026-09-30 Vēl vienkāršāks
    [table.scad]
